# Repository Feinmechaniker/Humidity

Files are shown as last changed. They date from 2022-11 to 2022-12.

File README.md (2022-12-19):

# Humidity-Controller
Humidity-Control, basierend auf einem ESP8266, bestimmt die Temperatur und die relative Luftfeuchtigkeit im Innen- und Außenbereich. Aus diesen Messdaten wird jede Minute für den Innen- und Außenbereich jeweils die absolute Luftfeuchtigkeit in g/m³ berechnet. In Abhängigkeit einer dynamischen Hystereseschwelle kann über ein Relais ein Lüfter angesteuert werden. Liegt die absolute Feuchte im Innenraum über der absoluten Feuchte im Außenbereich und ist die minimale Außentemperatur noch nicht erreicht, wird der Lüfter eingeschaltet. Die Hysterese wird automatisch dynamisch über die minimale Außentemperatur und die Genauigkeit der Feuchtesensoren berechnet. 
Das Zusamenspiel der einzelnen Komponenten zeigt die nachfolgende Abbildung.

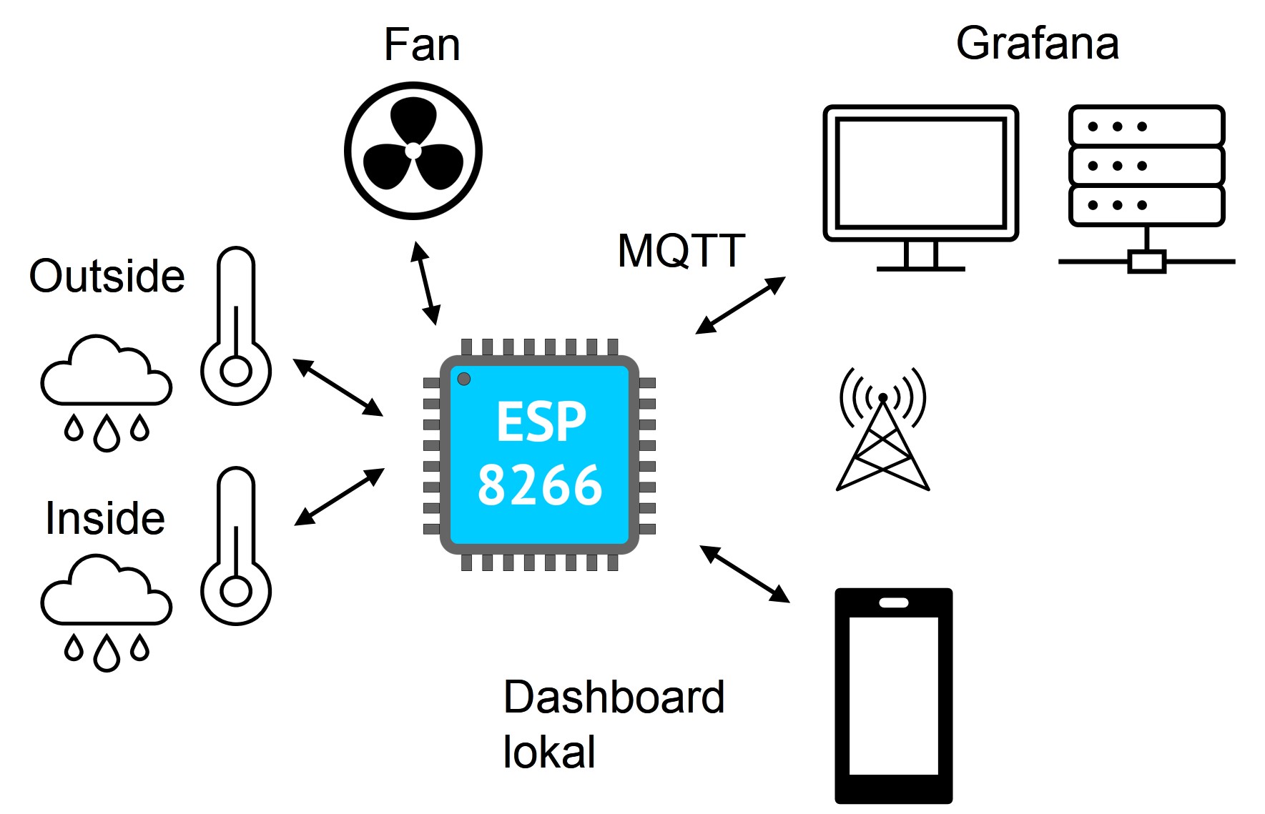
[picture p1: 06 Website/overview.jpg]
Übersicht


Optional können auf einem OLED-Display die aktuellen Temperaturen und die absoluten Feuchten abgelesen werden.

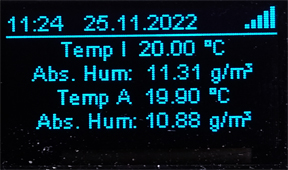
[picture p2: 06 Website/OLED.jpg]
OLED


## Dashboard lokal
Ein Dashboard auf einem lokalen Webserver des Controllers ermöglich Abfrage bzw. Änderung
- des Schaltzustandes des Lüfters
- der minimalen Schalttemperatur
- der Temperaturen im Innen- und Außenbereich
- der relativen und absoluten Luftfeuchtigkeiten im Innen- und Außenbereich

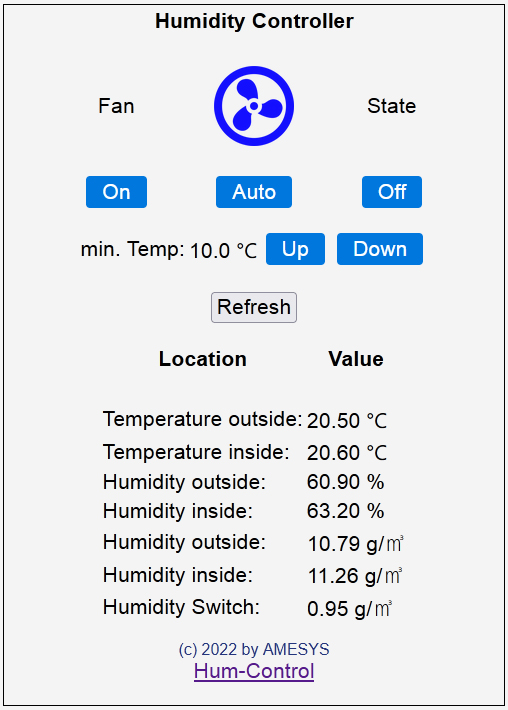
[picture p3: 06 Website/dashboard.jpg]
Dashboard


## Dashboard Grafana
Bei Bedarf werden sowohl die Messdaten als auch die daraus berechneten Ergebnisse über MQTT an eine Datenbank gesendet. Diese können dann über eine grafische Visualisierung wie z.B. Grafana dargestellt werden. 

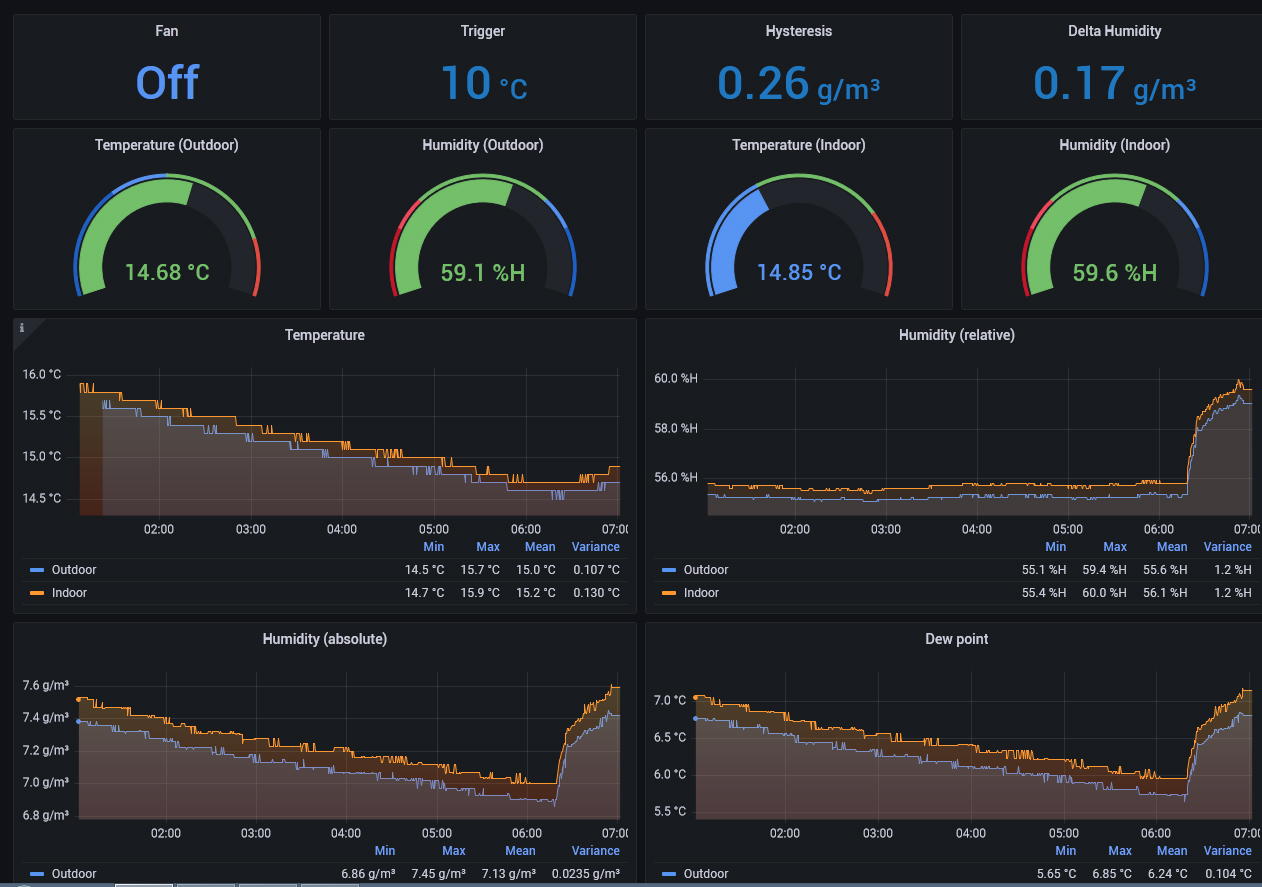
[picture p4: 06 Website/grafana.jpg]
Grafana


(c) 2022 Joe.G

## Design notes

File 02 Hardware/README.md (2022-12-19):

# Humidity-Controller
Die Hardware besteht aus einem NodeMCU Lua Amica Modul V2 ESP8266 Board, einem Netzteil und einer Relaisschaltung, welche über einen Optokoppler von der DC-Seite getrennt ist. Die Leiterplatte befindet sich in einem Z108 Hutschienengehäuse.  

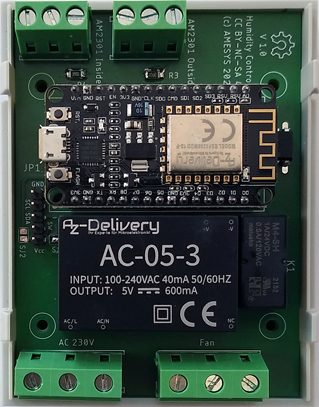
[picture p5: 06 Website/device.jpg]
Hardware


Leiterplatten können unter:
https://aisler.net/p/RMIZEMKT
bezogen werden.

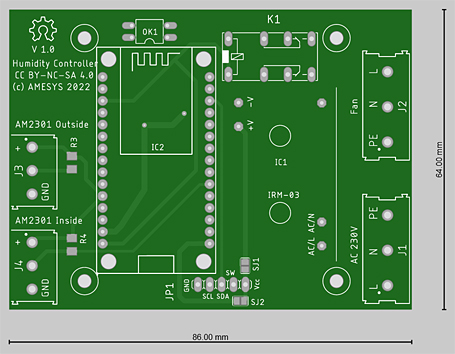
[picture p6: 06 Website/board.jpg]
Board


(c) 2022 Joe.G

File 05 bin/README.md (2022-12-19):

# Humidity-Controller
Die Software basiert auf dem ESPEasy-System:
https://github.com/letscontrolit/ESPEasy
Die Entwickler verbessern und erweitern dieses System ständig. Um mit dem derzeitigen Softwarestand kompatibel zu sein, sollte die hier abgespeicherte Binary-Version (16.06.2022) verwendet werden. Mit dieser Version sind alle Rules (rules1 - rules3) getestet. Weiterhin sollten die Devices wie abgebildet installiert werden. Wer die manuelle Konfiguration nicht selbst durchführen möchte, importiert die Datei config.dat.    

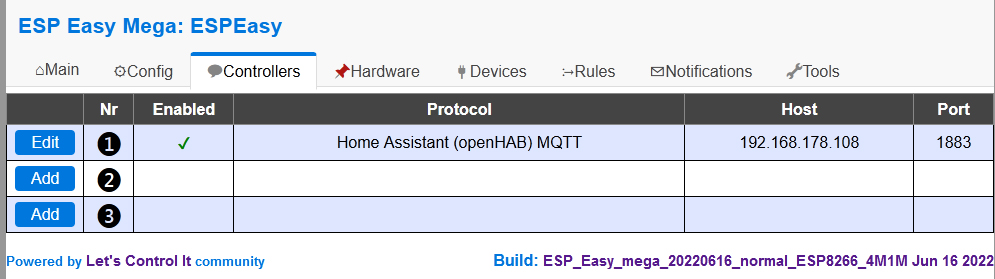
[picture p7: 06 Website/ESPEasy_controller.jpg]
Controller

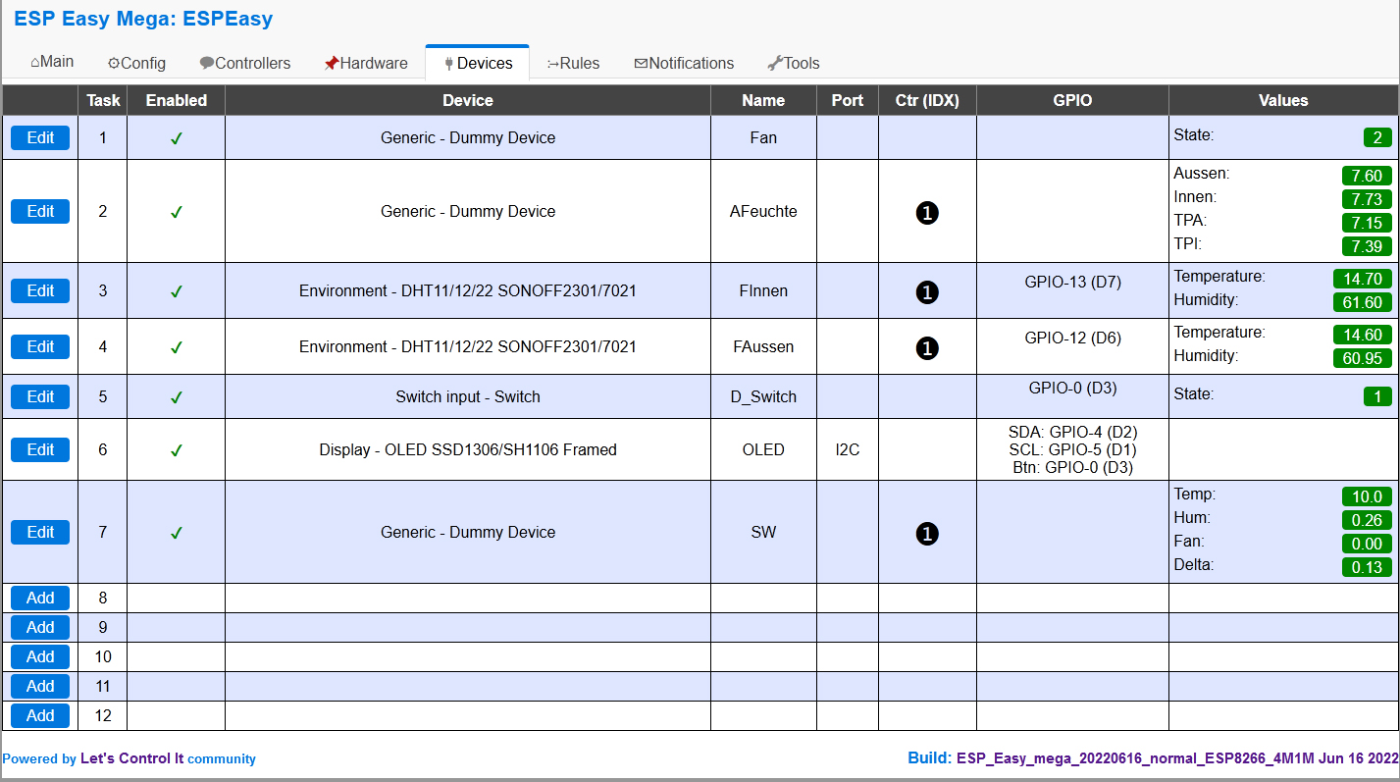
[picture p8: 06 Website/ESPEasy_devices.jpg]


(c) 2022 Joe.G

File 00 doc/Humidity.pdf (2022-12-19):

### Berechnung der absoluten Feuchte

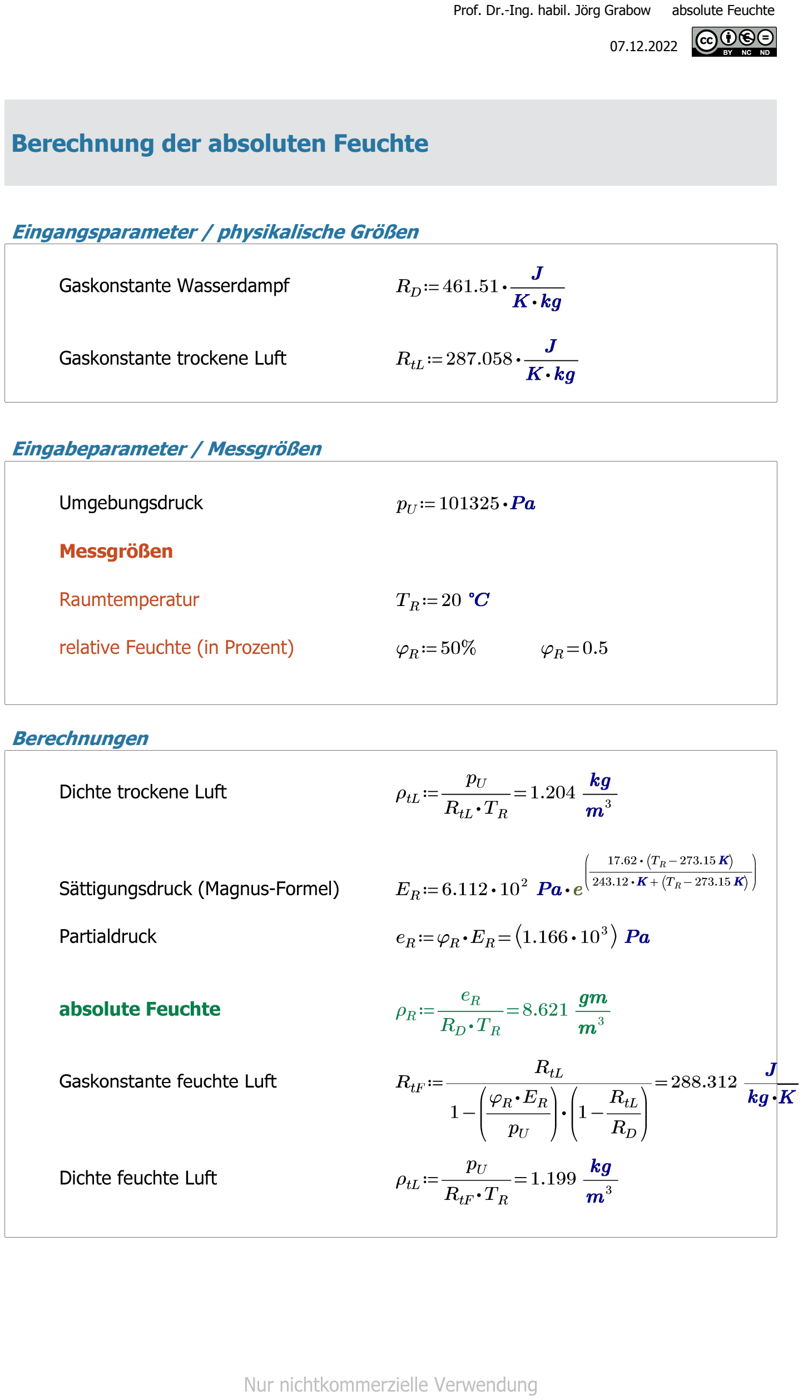
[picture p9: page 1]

Prof. Dr.-Ing. habil. Jörg Grabow absolute Feuchte

07.12.2022

Eingangsparameter / physikalische Größen

Eingabeparameter / Messgrößen

Berechnungen

K

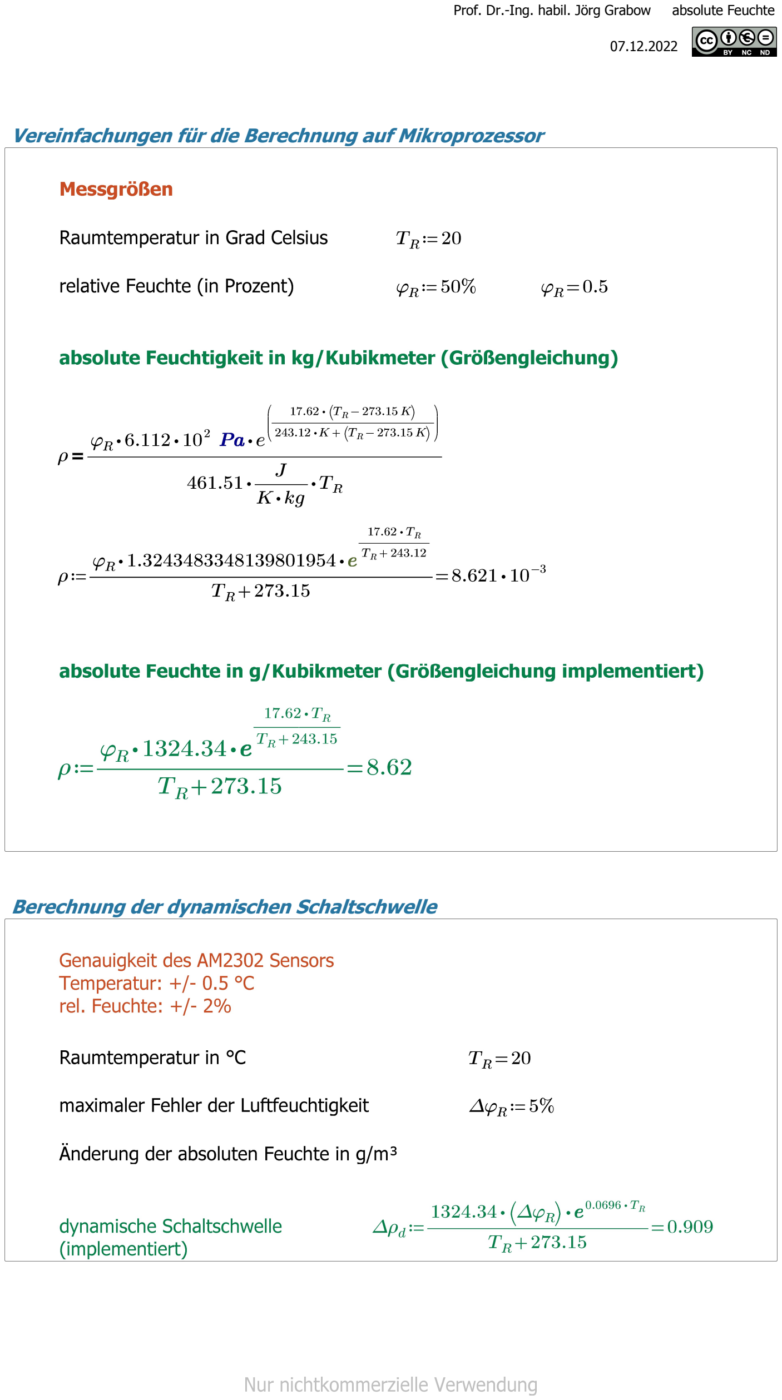
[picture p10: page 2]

Vereinfachungen für die Berechnung auf Mikroprozessor

Berechnung der dynamischen Schaltschwelle

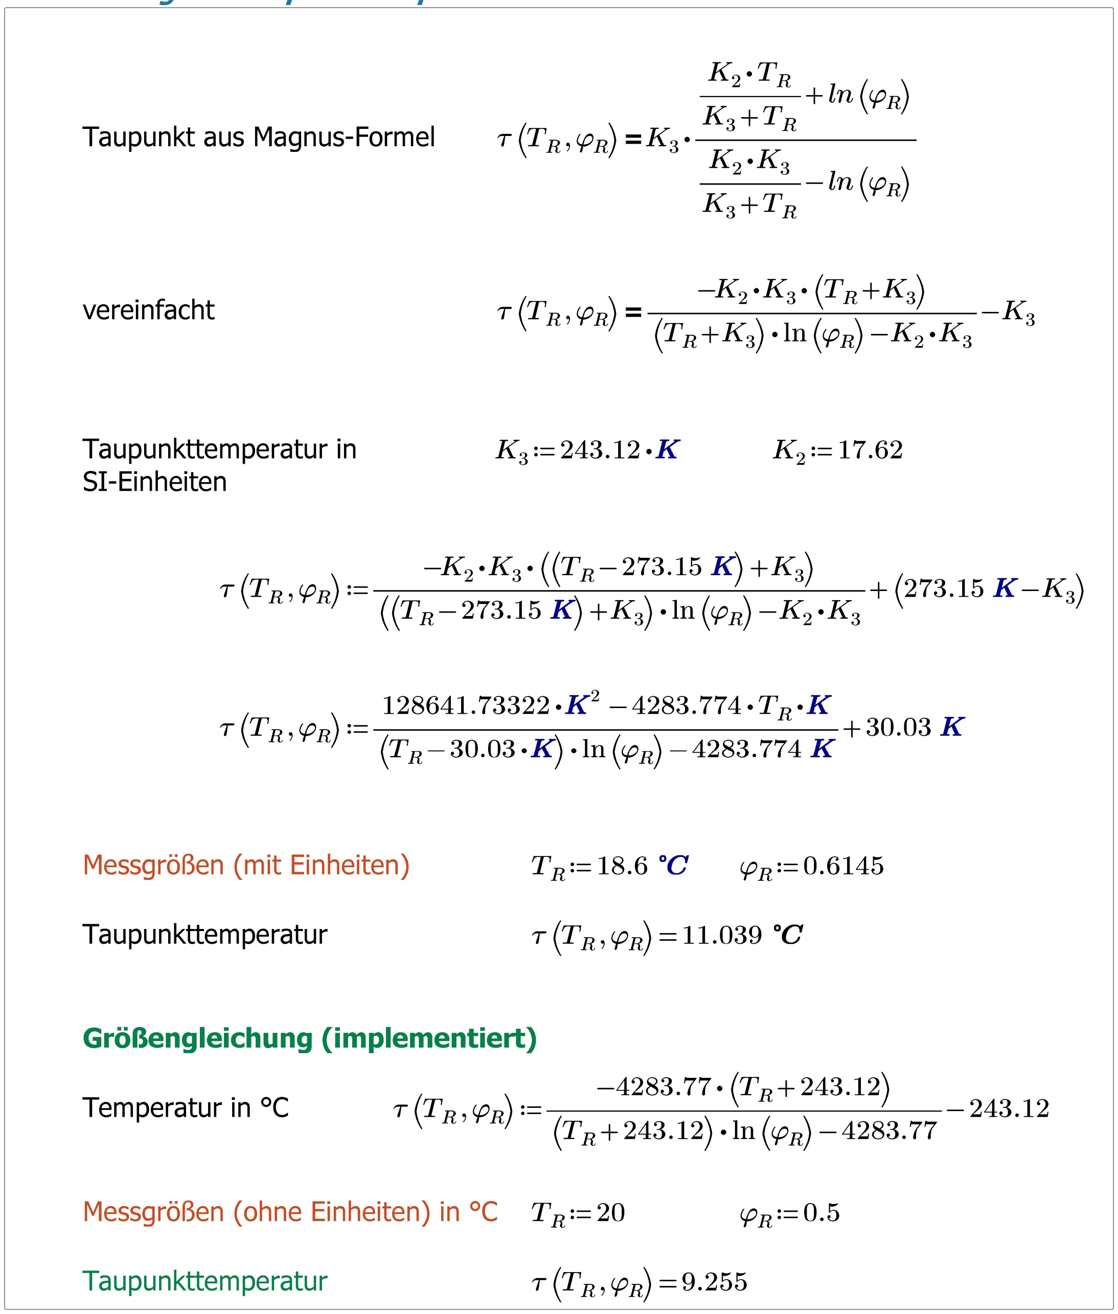
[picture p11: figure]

Berechnung der Taupunkttemperatur

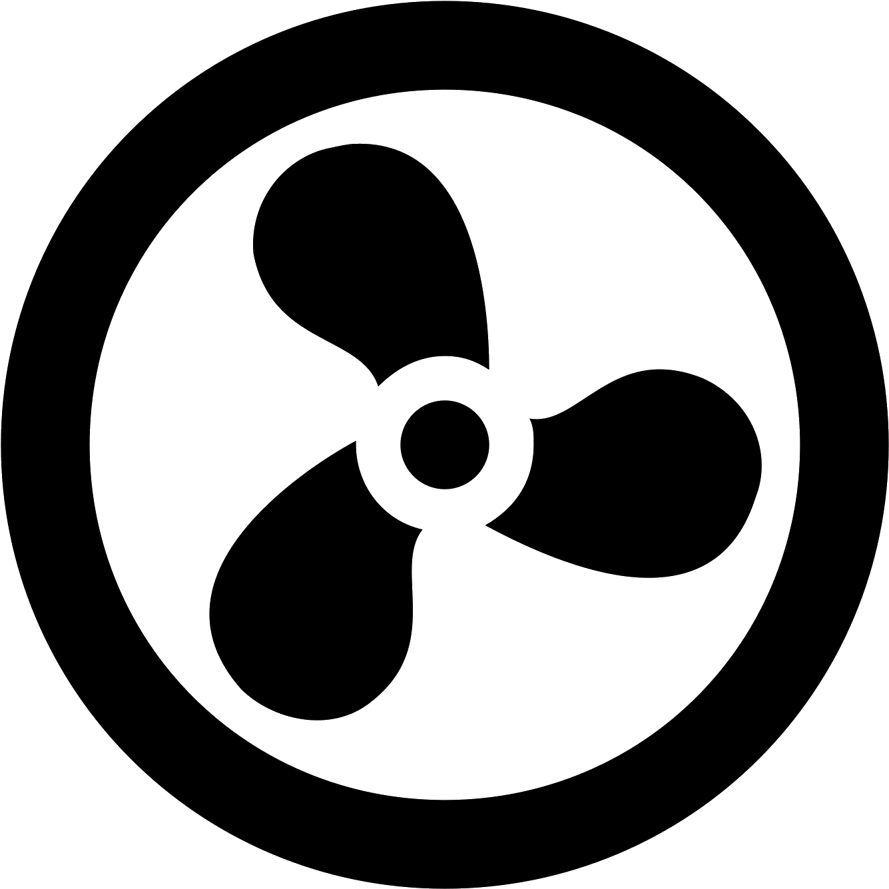
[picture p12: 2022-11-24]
04 Dashboard/fan0.png

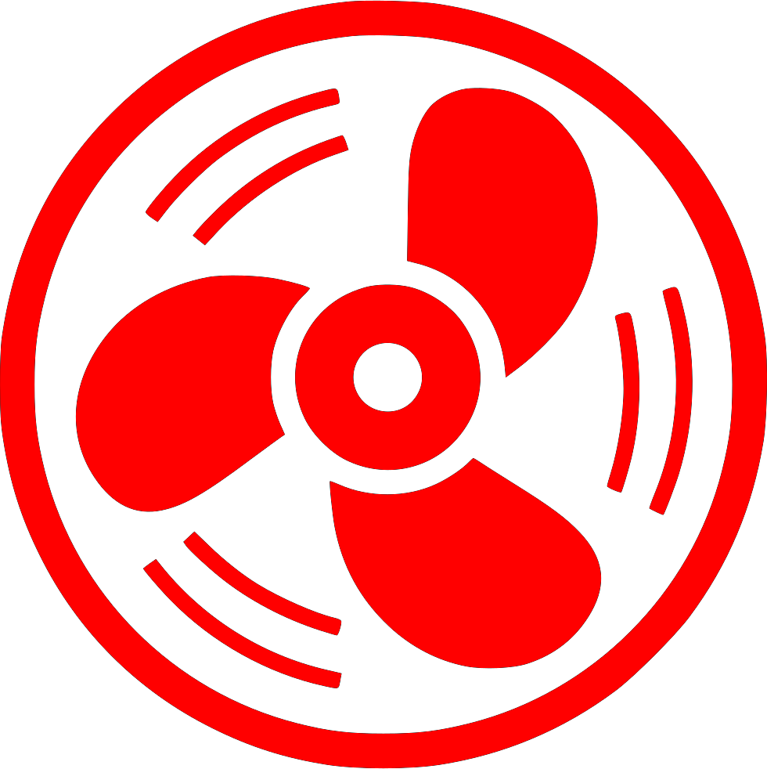
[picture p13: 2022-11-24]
04 Dashboard/fan1.png

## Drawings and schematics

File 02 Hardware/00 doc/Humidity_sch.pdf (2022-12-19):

A

A

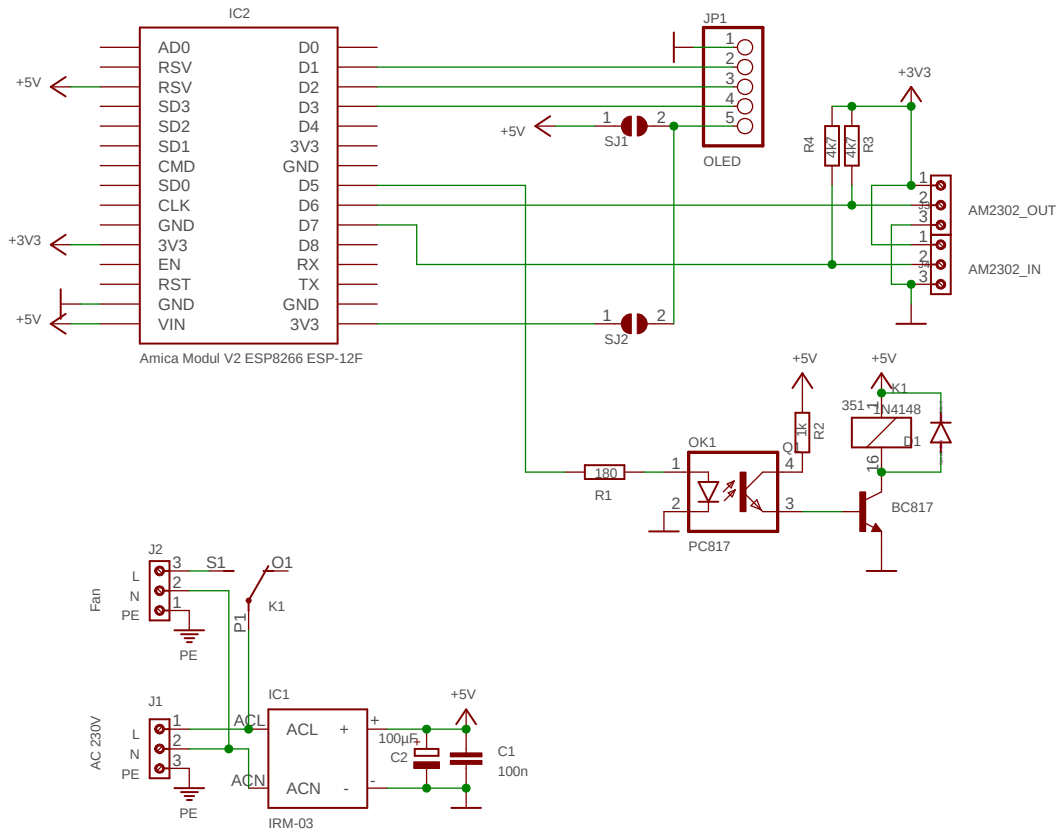
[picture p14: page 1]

(c) AMESYS 2022

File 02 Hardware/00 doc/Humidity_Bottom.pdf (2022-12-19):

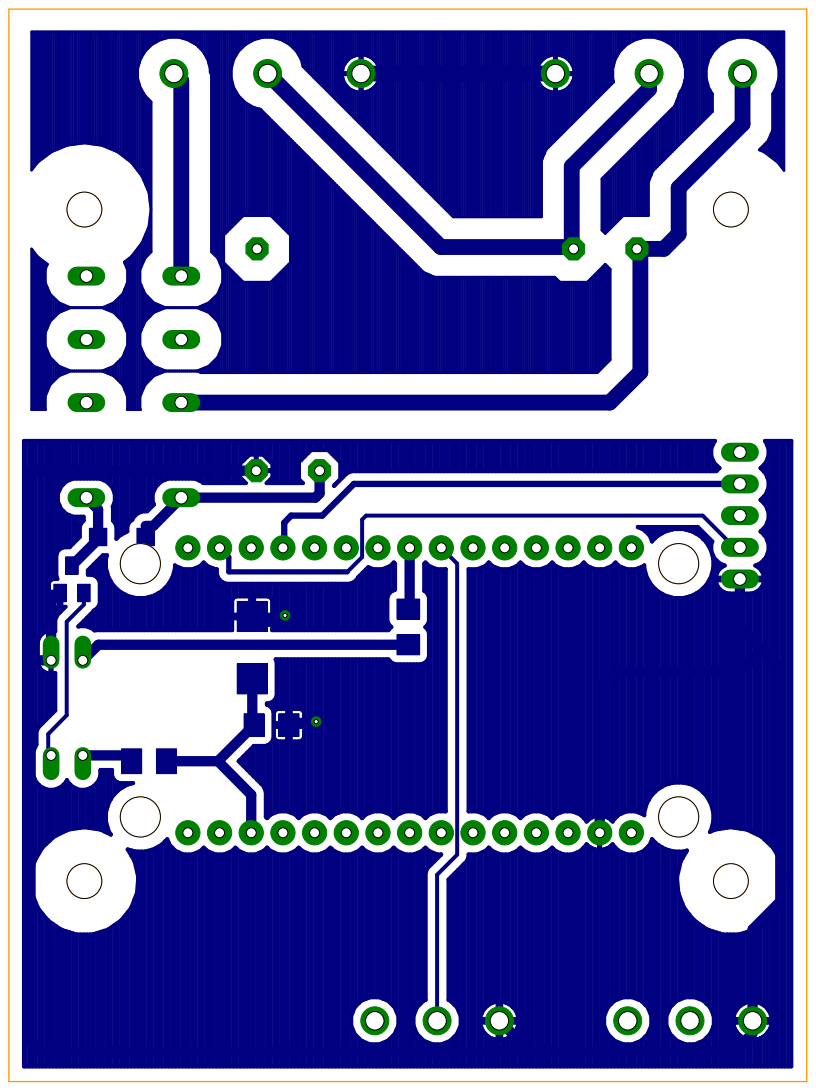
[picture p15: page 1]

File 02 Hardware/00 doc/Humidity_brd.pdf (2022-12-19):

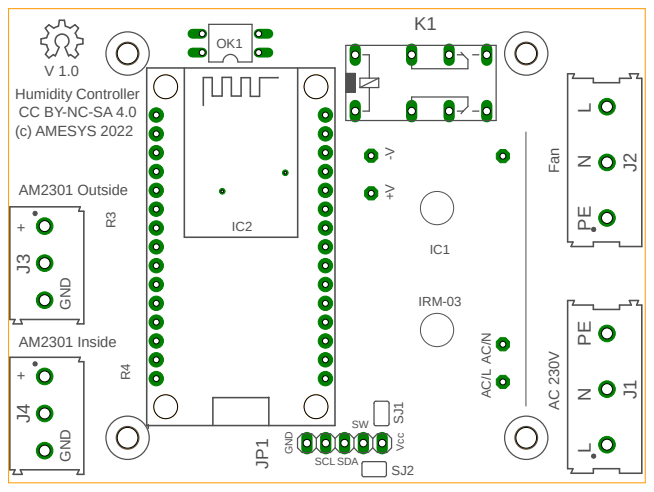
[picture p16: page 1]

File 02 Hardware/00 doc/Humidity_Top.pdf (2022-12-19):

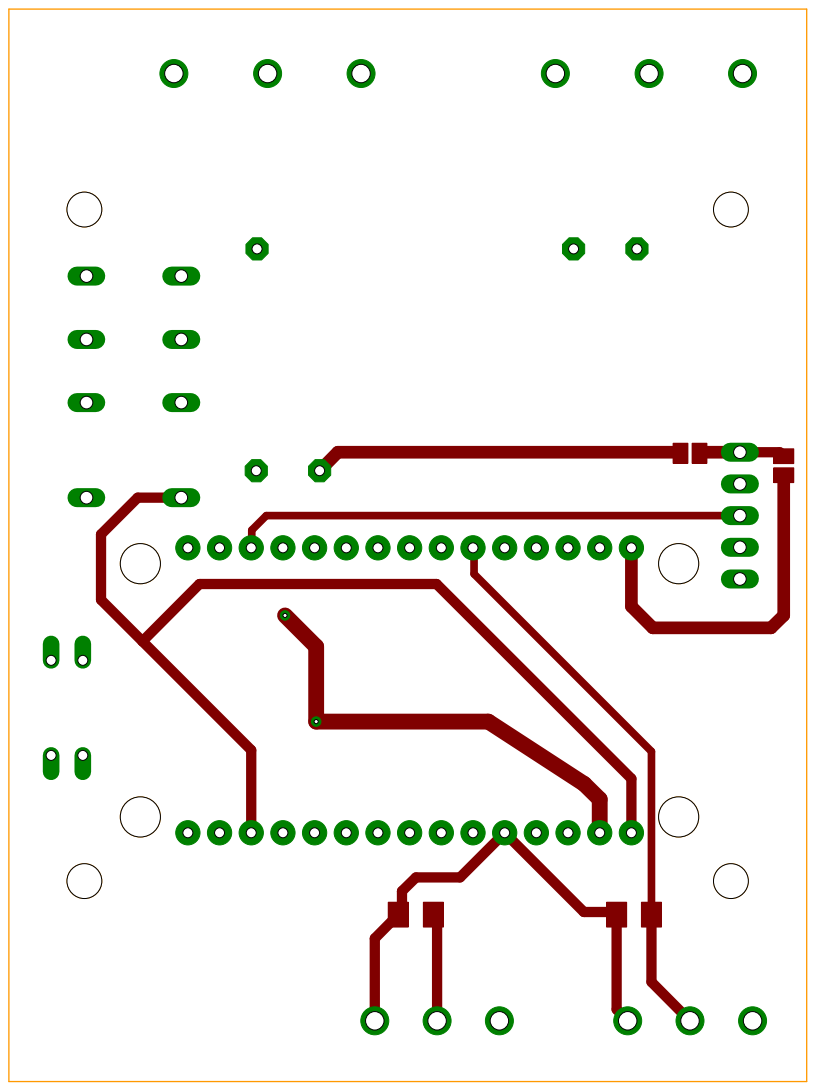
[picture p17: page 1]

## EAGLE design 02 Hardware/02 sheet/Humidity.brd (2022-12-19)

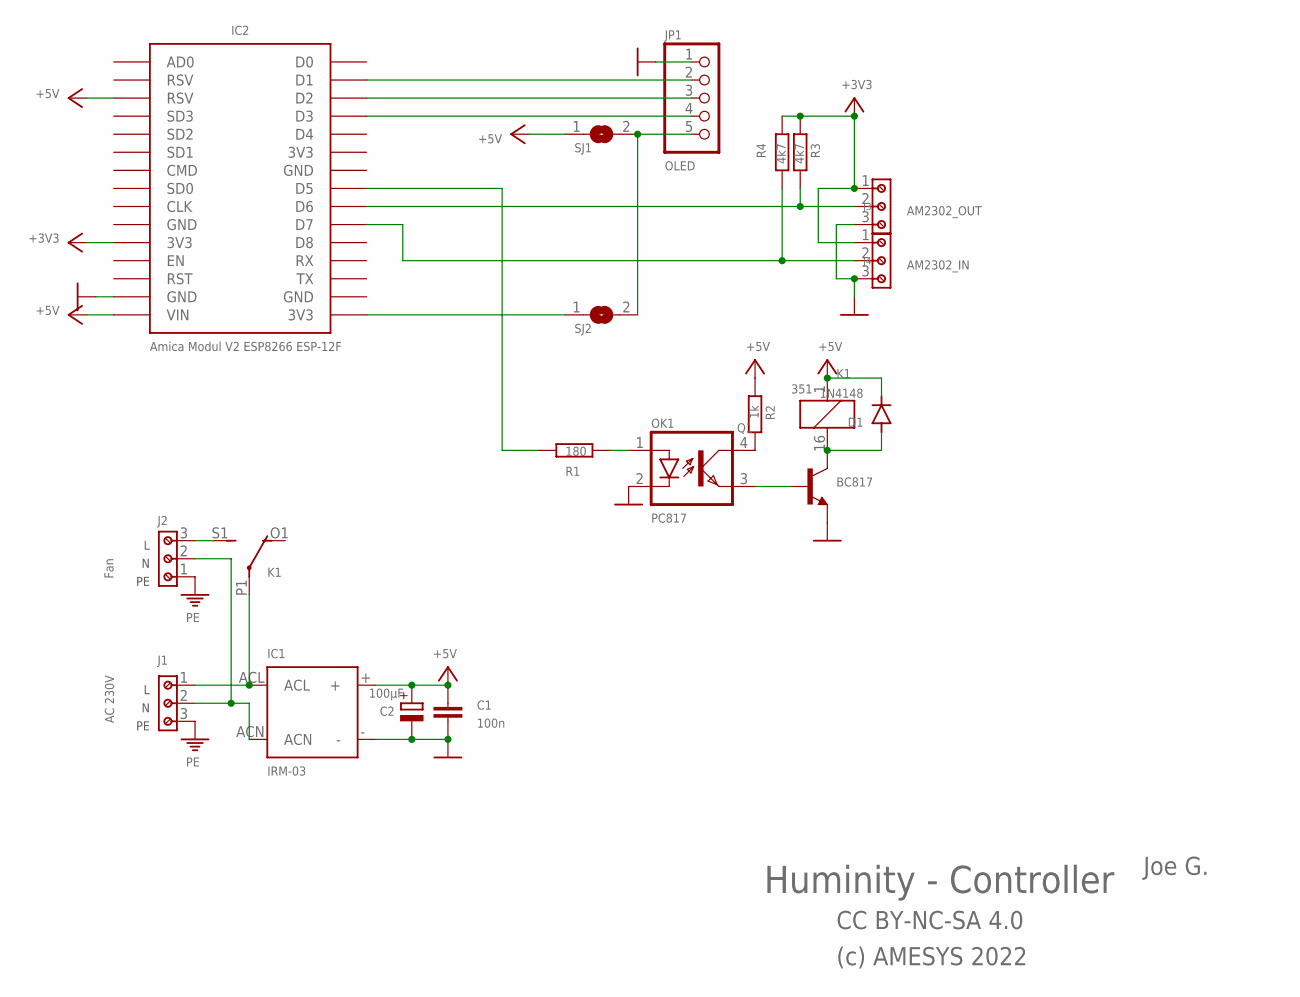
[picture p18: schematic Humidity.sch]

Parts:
C1: 100n; C1206
C2: 100µF; SMC_C
D1: 1N4148; SOD123
IC1: IRM-03
IC2: Amica Modul V2 ESP8266 ESP-12F; ESP12E_DEVKIT
J1: AC 230V; 691216910003
J2: Fan; 691216910003
J3: AM2302_OUT; 691216710003
J4: AM2302_IN; 691216710003
JP1: OLED; 1X05
K1: 351
OK1: PC817; DIL04
Q1: BC817; TRANSISTOR-NPN_SOT23-BEC
R1: 180; R1206
R2: 1k; M1206
R3, R4: 4k7; M1206
SJ1, SJ2: SJ

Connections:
+3V3: IC2.3V3@0 (3V3), J3.1, J4.1, R3.1, R4.1
+5V: C1.1, C2.+, D1.C, IC1.+, IC2.RSV@1 (RSV), IC2.VIN, K1.1, R2.1, SJ1.1
GND: C1.2, C2.-, IC1.-, IC2.GND@1 (GND), J3.3, J4.3, JP1.1, OK1.2 (C), Q1.E
unnamed: IC2.D6, J3.2, R3.2
unnamed: IC2.D7, J4.2, R4.2
unnamed: JP1.5, SJ1.2, SJ2.2
unnamed: IC1.ACL, J1.1, K1.P1
unnamed: IC1.ACN, J1.2, J2.2
unnamed: OK1.1 (A), R1.2
unnamed: OK1.4 (COL), R2.2
unnamed: D1.A, K1.16 (2), Q1.C
unnamed: OK1.3 (EMIT), Q1.B
unnamed: J2.3, K1.S1 (S)
unnamed: IC2.D1, JP1.2
unnamed: IC2.D2, JP1.3
unnamed: IC2.D3, JP1.4
unnamed: IC2.3V3@2 (3V3), SJ2.1
PE: J1.3, J2.1
REL: IC2.D5, R1.1

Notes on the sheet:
Huminity - Controller
CC BY-NC-SA 4.0
(c) AMESYS 2022
Joe G.

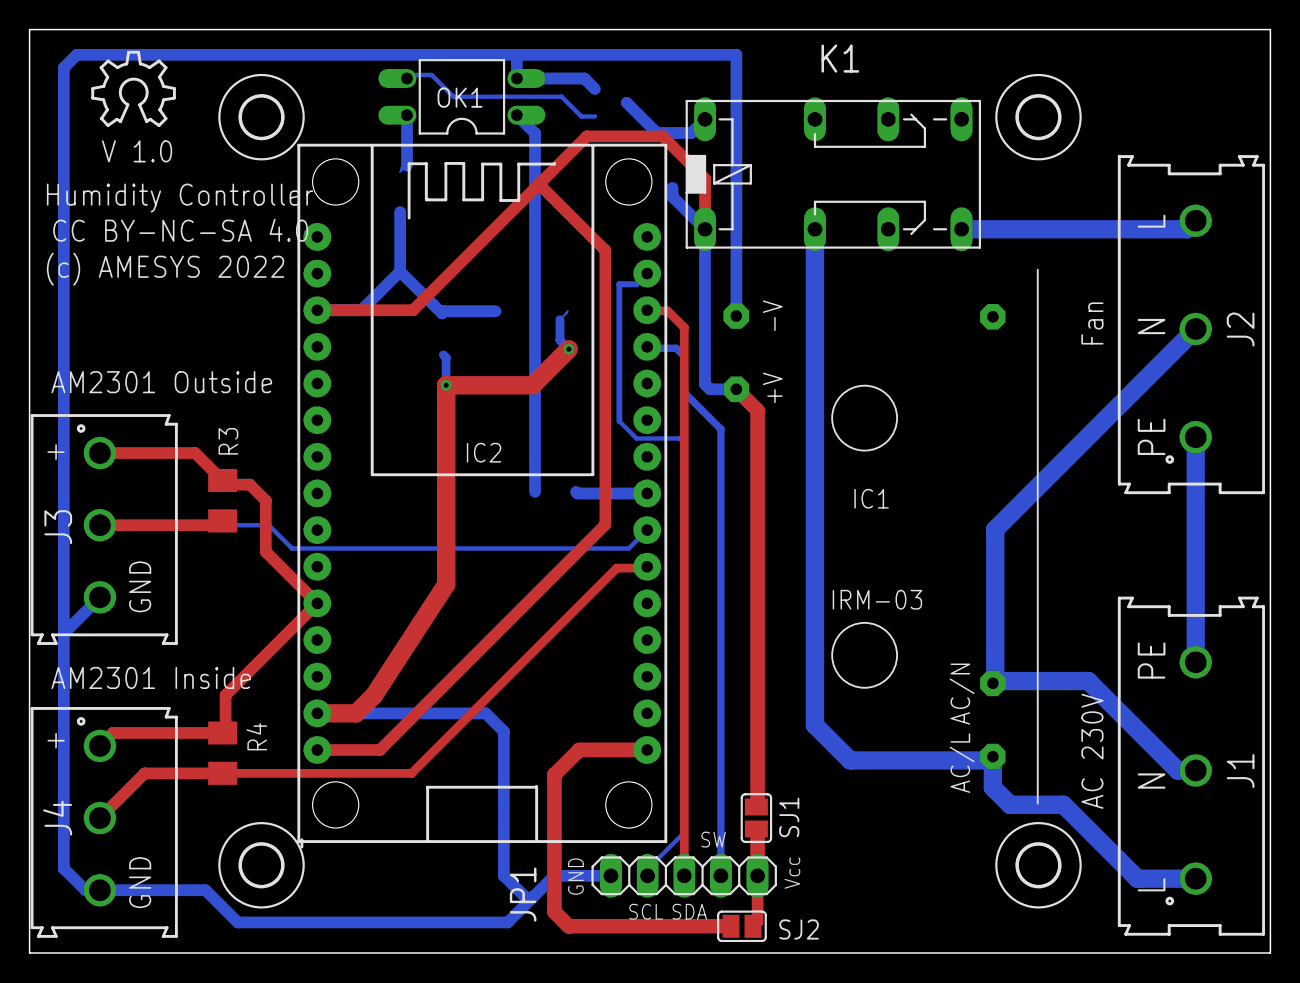
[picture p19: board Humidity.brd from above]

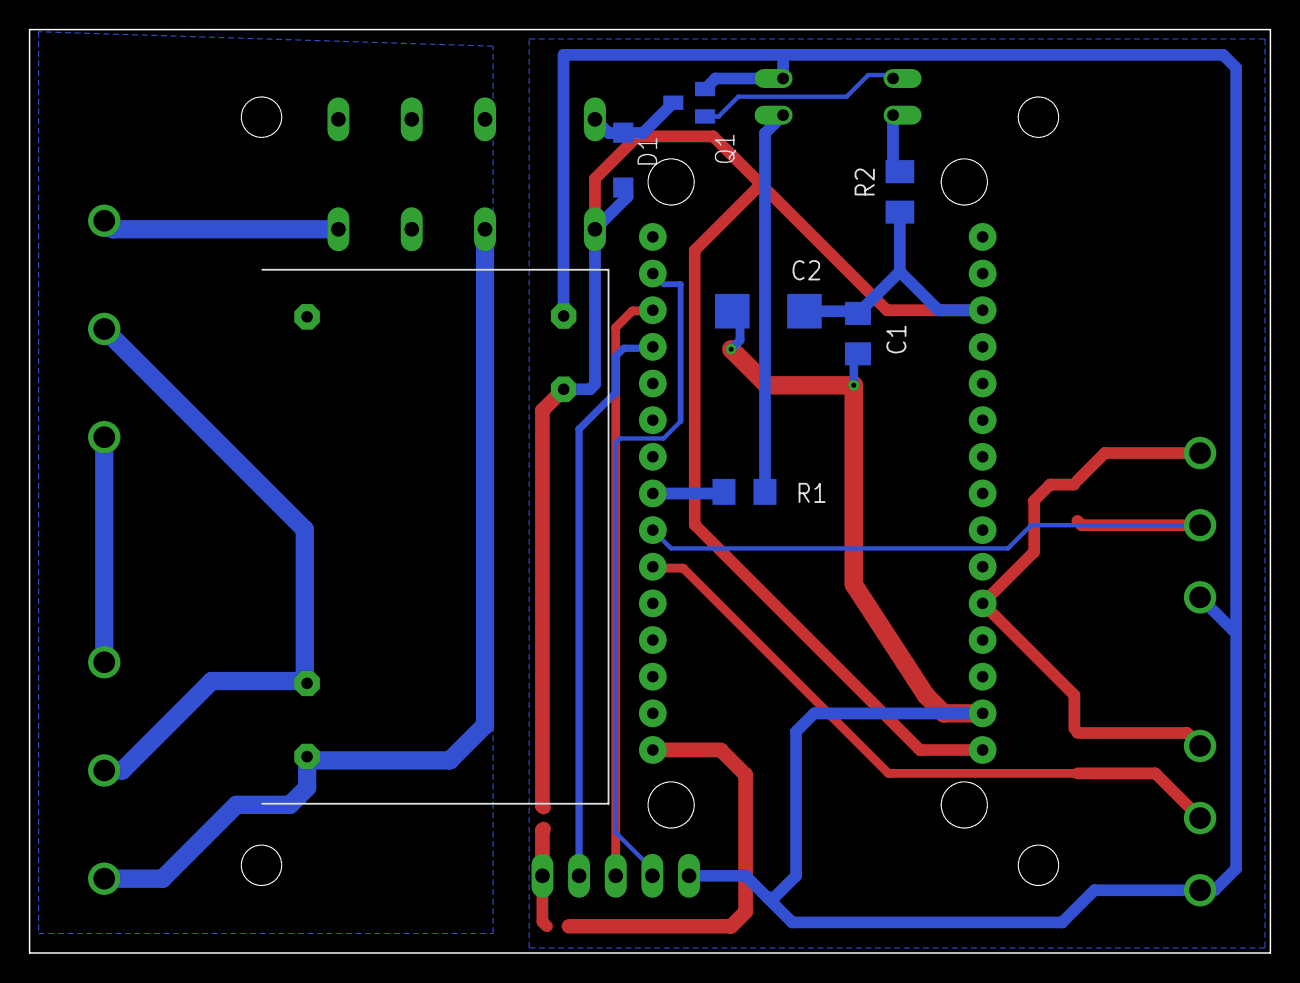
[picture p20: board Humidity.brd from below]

Board: 2 copper layers, 86.0 x 64.0 mm, 24 parts (6 on the bottom side), 19 nets.

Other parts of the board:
U$1, U$3, U$4, U$5: 2,8
U$7: OSHW_8X200_NOTEXT

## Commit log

2022-12-10 with AMICA Package
    [Humidity.brd, Humidity.sch]
2022-12-19 Dugfix Boarddesign
    [Humidity.brd, Humidity.sch]
2022-12-19 Board Design

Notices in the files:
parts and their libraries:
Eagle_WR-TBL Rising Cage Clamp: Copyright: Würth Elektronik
